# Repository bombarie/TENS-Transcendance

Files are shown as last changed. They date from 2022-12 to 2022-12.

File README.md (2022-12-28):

# TENS-Transcendance

Hardware design and code related to the development of a remotely-triggerable system of TENS muscle stimulation as part of the experimental dance / VR performance [Transcendance](https://www.theaterutrecht.nl/voorstellingen/transcendance).

The system extends an existing TENS muscle stimulator, the [Promed TENS 1000S](https://www.promed.de/soft-therapy/electrical-pain-therapy/144/promed-pain-therapy-device-tens-1000-s) and makes it controllable with OpenSoundControl (OSC) via WiFi through the use of an ESP32 microcontroller.

### Included in this repository 

**Software**
  - The [Arduino](https://www.arduino.cc/) code for the ESP32 microcontroller.
  - The code for the [Processing](https://processing.org/) sketch which served as a proxy between the ESP32 and a [TouchDesigner](https://derivative.ca/) patch (not by me) that was heavily integrating most of the performance.

**Hardware**
- The hardware designs to split a single TENS output channel to up to 16 different target locations. The PCB was designed in [KiCad](https://www.kicad.org/) 6.0.
- The additional libraries used in KiCad while designing the PCB are included in the repository.

### Dependencies

The software dependencies are enumerated in the Arduino and Processing folders.

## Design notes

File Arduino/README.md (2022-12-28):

# Arduino code

The sketch _Transcendence\_v06\_improved\_feedback\_to\_p5_ is the most recent.

### Hardware

The target device for this code is the [DOIT ESP32 DEVKIT V1](https://grobotronics.com/esp32-development-board-devkit-v1.html?sl=en) ESP32.

In the Arduino environment the ESP32 package 2.0.5 was used.

DOIT ESP32 DEVKIT V1 pinout

### Dependencies

- the WiFi + OSC library for the ESP32: [https://github.com/hideakitai/ArduinoOSC](https://github.com/hideakitai/ArduinoOSC)
- the code for addressing the CD74HC4067 16-channel multiplexer was taken from [http://adam-meyer.com/arduino/CD74HC4067](http://adam-meyer.com/arduino/CD74HC4067)
- the code for the MCP42100 digital potentiometer from DFRobot was taken from their product wiki: [https://wiki.dfrobot.com/Dual_Digital_Pot__100K__SKU__DFR0520#target_4](https://wiki.dfrobot.com/Dual_Digital_Pot__100K__SKU__DFR0520#target_4)

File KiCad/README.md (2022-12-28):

# KiCad designs

For this project we used a [Promed TENS 1000S](https://www.promed.de/soft-therapy/electrical-pain-therapy/144/promed-pain-therapy-device-tens-1000-s) TENS muscle stimulator, however there was a need to create multiple outputs, with these not needing to be active simultaneously. The TENS Output Board was designed in KiCad 6.x to support this use case. It houses a [CD74HC4067 16-channel multiplexer](https://www.sparkfun.com/products/9056) board and the switching is done using [Vishay VOR1142A6](https://www.digikey.com/en/products/detail/vishay-semiconductor-opto-division/VOR1142A6/6174564) mosfet relays.

Pressed for time the board was designed with ample room for further miniaturisation. Using solely through-hole components and spaced widely it has a distinctly oldschool look which I don't hate :)

### board layout
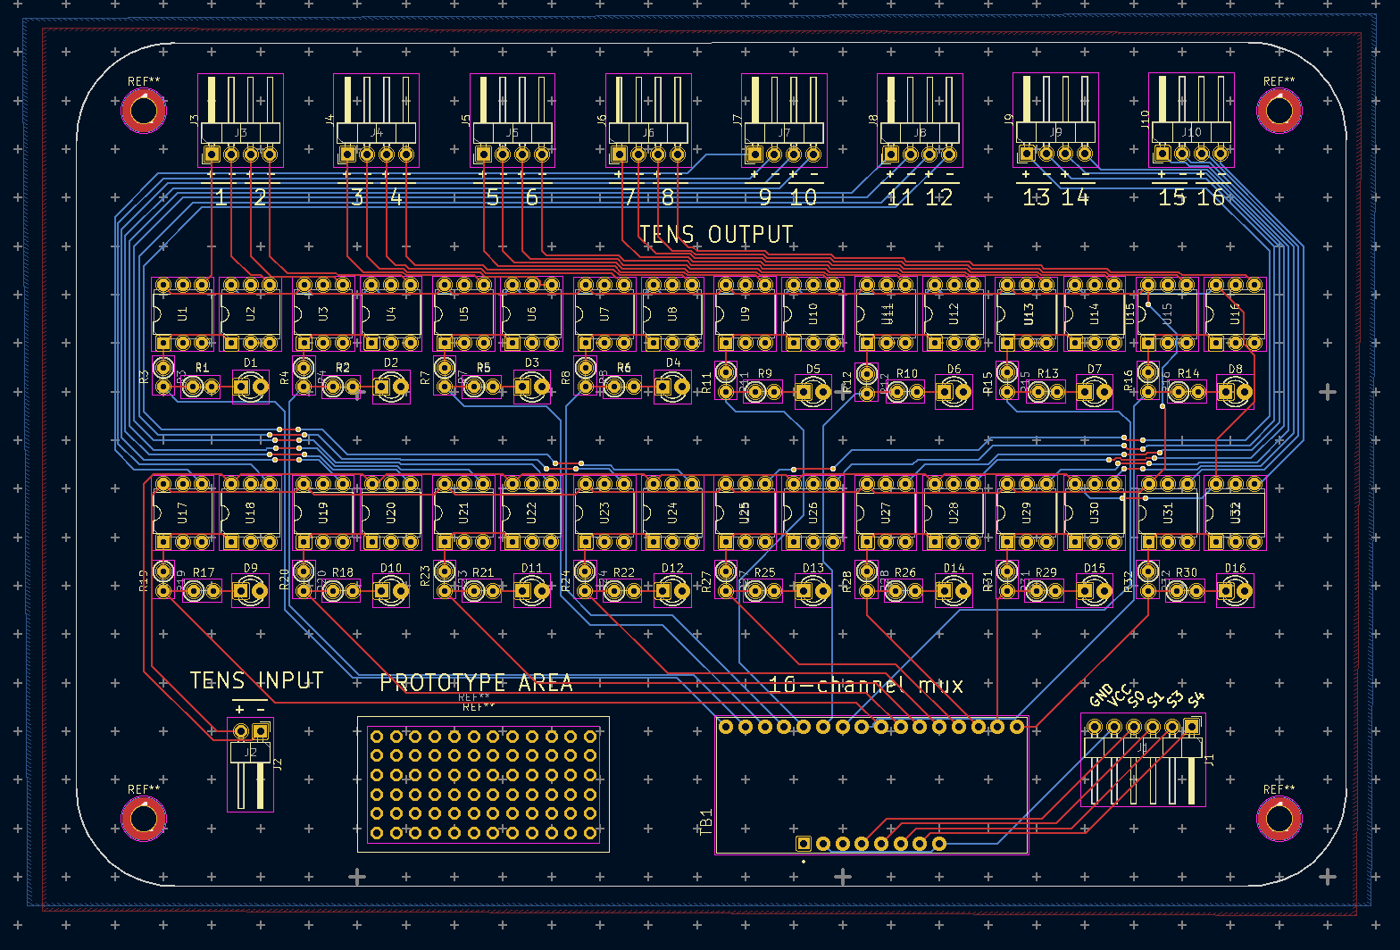
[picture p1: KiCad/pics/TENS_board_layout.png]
TENS switching board layout


### 3d preview
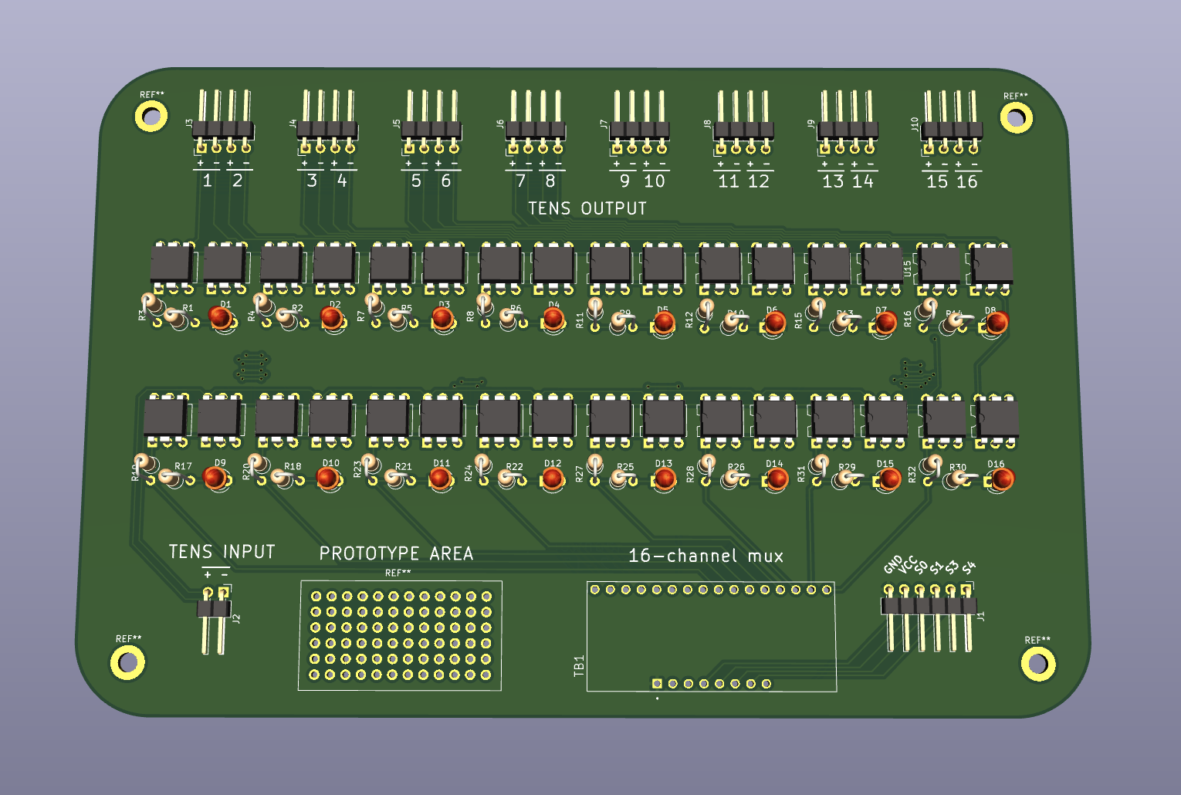
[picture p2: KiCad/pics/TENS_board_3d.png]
TENS switching board 3d preview


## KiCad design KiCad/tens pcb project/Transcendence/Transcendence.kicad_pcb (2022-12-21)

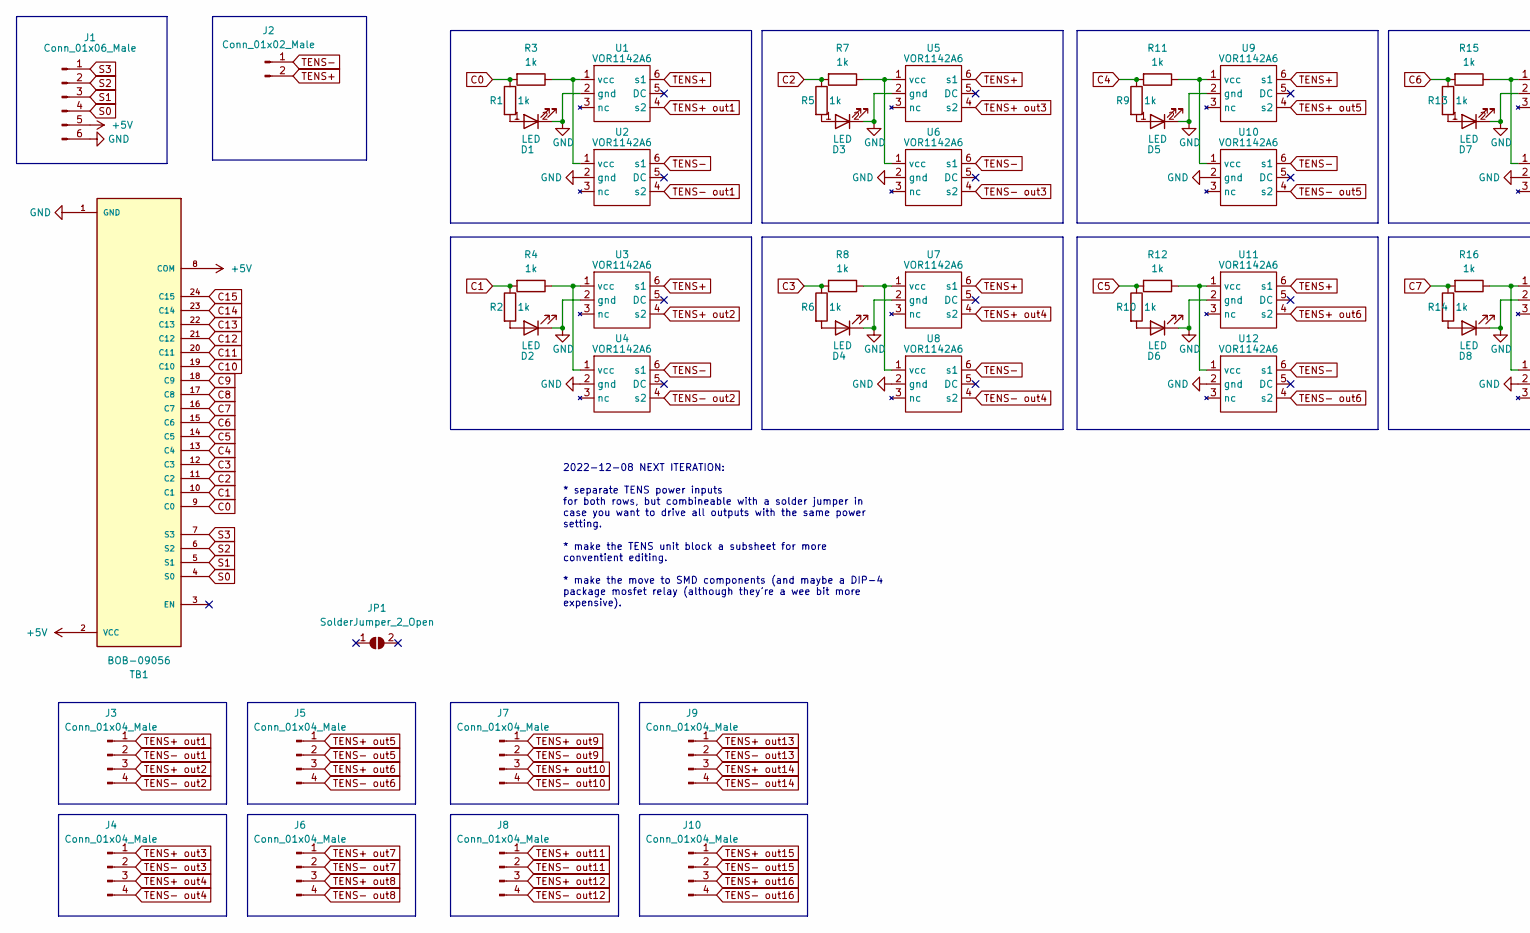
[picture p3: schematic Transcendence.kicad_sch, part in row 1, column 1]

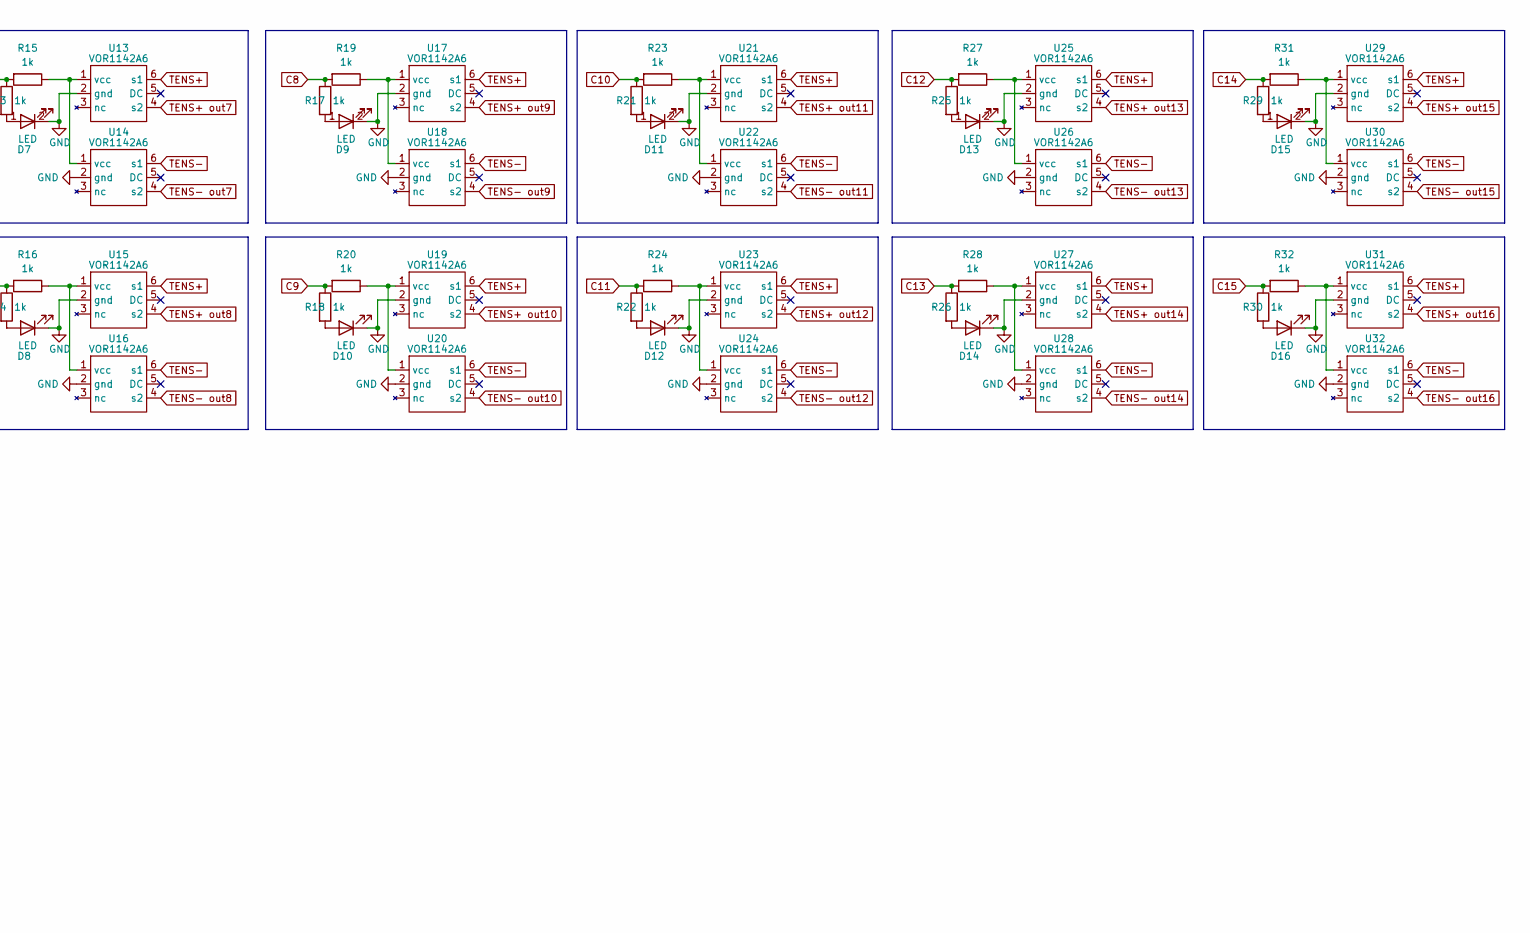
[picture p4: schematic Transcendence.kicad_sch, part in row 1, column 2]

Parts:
D1, D2, D3, D4, D5, D6, D7, D8, D9, D10, D11, D12, D13, D14, D15, D16: LED; LED_D3.0mm
J1: Conn_01x06_Male; PinHeader_1x06_P2.54mm_Horizontal
J2: Conn_01x02_Male; PinHeader_1x02_P2.54mm_Horizontal
J3, J4, J5, J6, J7, J8, J9, J10: Conn_01x04_Male; PinHeader_1x04_P2.54mm_Horizontal
JP1: SolderJumper_2_Open; SolderJumper-2_P1.3mm_Open_Pad1.0x1.5mm
R1, R2, R3, R4, R5, R6, R7, R8, R9, R10, R11, R12, R13, R14, R15, R16, R17, R18, R19, R20, R21, R22, R23, R24, R25, R26, R27, R28, R29, R30, R31, R32: 1k; R_Axial_DIN0207_L6.3mm_D2.5mm_P2.54mm_Vertical
TB1: BOB-09056; XDCR_BOB-09056; PARTREV N/A
U1, U2, U3, U4, U5, U6, U7, U8, U9, U10, U11, U12, U13, U14, U15, U16, U17, U18, U19, U20, U21, U22, U23, U24, U25, U26, U27, U28, U29, U30, U31, U32: VOR1142A6; DIP-6_W7.62mm

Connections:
+5V: J1.5, TB1.2 (VCC), TB1.8 (COM)
C0: R1.1, R3.2, TB1.9 (C0)
C1: R2.1, R4.2, TB1.10 (C1)
C2: R5.1, R7.2, TB1.11 (C2)
C3: R6.1, R8.2, TB1.12 (C3)
C4: R9.1, R11.2, TB1.13 (C4)
C5: R10.1, R12.2, TB1.14 (C5)
C6: R13.1, R15.2, TB1.15 (C6)
C7: R14.1, R16.2, TB1.16 (C7)
C8: R17.1, R19.2, TB1.17 (C8)
C9: R18.1, R20.2, TB1.18 (C9)
C10: R21.1, R23.2, TB1.19 (C10)
C11: R22.1, R24.2, TB1.20 (C11)
C12: R25.1, R27.2, TB1.21 (C12)
C13: R26.1, R28.2, TB1.22 (C13)
C14: R29.1, R31.2, TB1.23 (C14)
C15: R30.1, R32.2, TB1.24 (C15)
GND: D1.2 (K), D2.2 (K), D3.2 (K), D4.2 (K), D5.2 (K), D6.2 (K), D7.2 (K), D8.2 (K), D9.2 (K), D10.2 (K), D11.2 (K), D12.2 (K), D13.2 (K), D14.2 (K), D15.2 (K), D16.2 (K), J1.6, TB1.1 (GND), U1.2 (gnd), U2.2 (gnd), U3.2 (gnd), U4.2 (gnd), U5.2 (gnd), U6.2 (gnd), U7.2 (gnd), U8.2 (gnd), U9.2 (gnd), U10.2 (gnd), U11.2 (gnd), U12.2 (gnd), U13.2 (gnd), U14.2 (gnd), U15.2 (gnd), U16.2 (gnd), U17.2 (gnd), U18.2 (gnd), U19.2 (gnd), U20.2 (gnd), U21.2 (gnd), U22.2 (gnd), U23.2 (gnd), U24.2 (gnd), U25.2 (gnd), U26.2 (gnd), U27.2 (gnd), U28.2 (gnd), U29.2 (gnd), U30.2 (gnd), U31.2 (gnd), U32.2 (gnd)
unnamed: D1.1 (A), R1.2
unnamed: D2.1 (A), R2.2
unnamed: D3.1 (A), R5.2
unnamed: D4.1 (A), R6.2
unnamed: D5.1 (A), R9.2
unnamed: D6.1 (A), R10.2
unnamed: D7.1 (A), R13.2
unnamed: D8.1 (A), R14.2
unnamed: D9.1 (A), R17.2
unnamed: D10.1 (A), R18.2
unnamed: D11.1 (A), R21.2
unnamed: D12.1 (A), R22.2
unnamed: D13.1 (A), R25.2
unnamed: D14.1 (A), R26.2
unnamed: D15.1 (A), R29.2
unnamed: D16.1 (A), R30.2
unnamed: R3.1, U1.1 (vcc), U2.1 (vcc)
unnamed: R4.1, U3.1 (vcc), U4.1 (vcc)
unnamed: R7.1, U5.1 (vcc), U6.1 (vcc)
unnamed: R8.1, U7.1 (vcc), U8.1 (vcc)
unnamed: R11.1, U9.1 (vcc), U10.1 (vcc)
unnamed: R12.1, U11.1 (vcc), U12.1 (vcc)
unnamed: R15.1, U13.1 (vcc), U14.1 (vcc)
unnamed: R16.1, U15.1 (vcc), U16.1 (vcc)
unnamed: R19.1, U17.1 (vcc), U18.1 (vcc)
unnamed: R20.1, U19.1 (vcc), U20.1 (vcc)
unnamed: R23.1, U21.1 (vcc), U22.1 (vcc)
unnamed: R24.1, U23.1 (vcc), U24.1 (vcc)
unnamed: R27.1, U25.1 (vcc), U26.1 (vcc)
unnamed: R28.1, U27.1 (vcc), U28.1 (vcc)
unnamed: R31.1, U29.1 (vcc), U30.1 (vcc)
unnamed: R32.1, U31.1 (vcc), U32.1 (vcc)
S0: J1.4, TB1.4 (S0)
S1: J1.3, TB1.5 (S1)
S2: J1.2, TB1.6 (S2)
S3: J1.1, TB1.7 (S3)
TENS+: J2.2, U1.6 (s1), U3.6 (s1), U5.6 (s1), U7.6 (s1), U9.6 (s1), U11.6 (s1), U13.6 (s1), U15.6 (s1), U17.6 (s1), U19.6 (s1), U21.6 (s1), U23.6 (s1), U25.6 (s1), U27.6 (s1), U29.6 (s1), U31.6 (s1)
TENS+ out1: J3.1, U1.4 (s2)
TENS+ out2: J3.3, U3.4 (s2)
TENS+ out3: J4.1, U5.4 (s2)
TENS+ out4: J4.3, U7.4 (s2)
TENS+ out5: J5.1, U9.4 (s2)
TENS+ out6: J5.3, U11.4 (s2)
TENS+ out7: J6.1, U13.4 (s2)
TENS+ out8: J6.3, U15.4 (s2)
TENS+ out9: J7.1, U17.4 (s2)
TENS+ out10: J7.3, U19.4 (s2)
TENS+ out11: J8.1, U21.4 (s2)
TENS+ out12: J8.3, U23.4 (s2)
TENS+ out13: J9.1, U25.4 (s2)
TENS+ out14: J9.3, U27.4 (s2)
TENS+ out15: J10.1, U29.4 (s2)
TENS+ out16: J10.3, U31.4 (s2)
TENS-: J2.1, U2.6 (s1), U4.6 (s1), U6.6 (s1), U8.6 (s1), U10.6 (s1), U12.6 (s1), U14.6 (s1), U16.6 (s1), U18.6 (s1), U20.6 (s1), U22.6 (s1), U24.6 (s1), U26.6 (s1), U28.6 (s1), U30.6 (s1), U32.6 (s1)
TENS- out1: J3.2, U2.4 (s2)
TENS- out2: J3.4, U4.4 (s2)
TENS- out3: J4.2, U6.4 (s2)
TENS- out4: J4.4, U8.4 (s2)
TENS- out5: J5.2, U10.4 (s2)
TENS- out6: J5.4, U12.4 (s2)
TENS- out7: J6.2, U14.4 (s2)
TENS- out8: J6.4, U16.4 (s2)
TENS- out9: J7.2, U18.4 (s2)
TENS- out10: J7.4, U20.4 (s2)
TENS- out11: J8.2, U22.4 (s2)
TENS- out12: J8.4, U24.4 (s2)
TENS- out13: J9.2, U26.4 (s2)
TENS- out14: J9.4, U28.4 (s2)
TENS- out15: J10.2, U30.4 (s2)
TENS- out16: J10.4, U32.4 (s2)

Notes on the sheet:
2022-12-08 NEXT ITERATION: * separate TENS power inputs for both rows, but combineable with a solder jumper in case you want to drive all outputs with the same power setting. * make the TENS unit block a subsheet for more conventient editing. * make the move to SMD components (and maybe a DIP-4 pac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

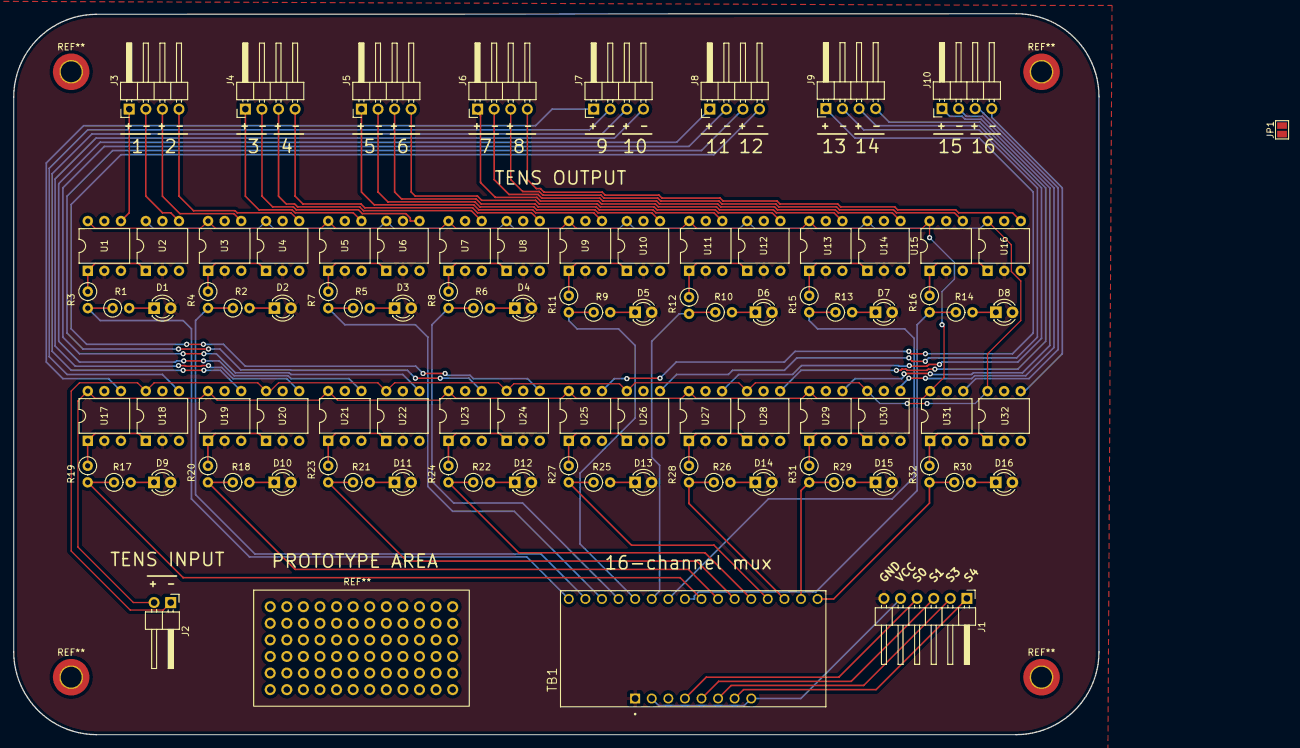
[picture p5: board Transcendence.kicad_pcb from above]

Board: 2 copper layers, 166.2 x 110.4 mm, 92 parts (0 on the bottom side), 88 nets.

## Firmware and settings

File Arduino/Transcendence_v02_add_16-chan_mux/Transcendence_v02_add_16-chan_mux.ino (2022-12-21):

// #define ARDUINOOSC_DEBUGLOG_ENABLE

// Please include ArduinoOSCWiFi.h to use ArduinoOSC on the platform
// which can use both WiFi and Ethernet
#include <ArduinoOSCWiFi.h>
// this is also valid for other platforms which can use only WiFi
// #include <ArduinoOSC.h>

#include <SPI.h>

/***********************PIN Definitions*************************/
// set pin 10 as the slave select (SS) for the digital pot
// for using Arduino UNO
//const int CS_PIN = 10; // Arduino Nano
const int CS_PIN = 5; // Doit ESP32 Wroom
//const int CS_PIN = 15; // Wemos D1 Mini

/***********************MCP42XXX Commands************************/
//potentiometer select byte
const int POT0_SEL = 0x11;
const int POT1_SEL = 0x12;
const int BOTH_POT_SEL = 0x13;

//shutdown the device to put it into power-saving mode.
//In this mode, terminal A is open-circuited and the B and W terminals are shorted together.
//send new command and value to exit shutdowm mode.
const int POT0_SHUTDOWN = 0x21;
const int POT1_SHUTDOWN = 0x22;
const int BOTH_POT_SHUTDOWN = 0x23;

/***********************Customized Varialbes**********************/
//resistance value byte (0 - 255)
//The wiper is reset to the mid-scale position upon power-up, i.e. POT0_Dn = POT1_Dn = 128
int POT0_Dn = 128;
int POT1_Dn = 128;
int BOTH_POT_Dn = 128;

// WiFi @ Theater Utrecht
//const char* ssid = "pkat";
//const char* pwd = "th3@t3r1";

// WiFi @ home
const char* ssid = "WormKoning";
const char* pwd = "dingflofbips";

// @home
const IPAddress ip(192, 168, 1, 201);
const IPAddress gateway(192, 168, 1, 1);

// @theater utrecht
//const IPAddress ip(192, 168, 72, 201);
//const IPAddress gateway(192, 168, 72, 1);
const IPAddress subnet(255, 255, 255, 0);

// for ArduinoOSC
//const char* host = "192.168.72.185"; // remote host @theater utrecht
const char* host = "192.168.1.147"; // remote host @home
const int recv_port = 54321;
const int bind_port = 54345;
const int send_port = 55555;
const int publish_port = 54445;

// Mux control pins (esp32)
static byte s0 = 26;
static byte s1 = 25;
static byte s2 = 33;
static byte s3 = 32;

byte sigIndex = 0; // mux output channel

int IdToChannel[4] = { 0, 1, 2, 3 };

// send / receive varibales
int i;
float f;
String s;

long startPulseTime;
int _pulseDuration;
bool IsPulsing = false;

// SHOULD BE TRUE (further down the line)
bool bUseHeartbeat = false;



int currTriggerID;
float pulseWidth = 0.0;     // range [0.0, 1.0] -> in reality maps to [30µs, 260µs]
float pulseFrequency = 0.0; // range [0.0, 1.0] -> in reality maps to [2Hz, 150Hz]
float pulseStrength = 0.0;  // range [0.0, 1.0] -> in reality maps to [0V, 75V]
int pulseDuration = 0;      // milliseconds
void onTriggerReceived(const OscMessage& m) {
  int id = m.arg<int>(0);
  pulseWidth = m.arg<float>(1);
  pulseFrequency = m.arg<float>(2);
  pulseStrength = m.arg<float>(3);
  pulseDuration = m.arg<int>(4);


  //  Serial.print(m.remoteIP());
  //  Serial.print(" ");
  //  Serial.print(m.remotePort());
  //  Serial.print(" ");
  //  Serial.print(m.size());
  //  Serial.print(" ");
  //  Serial.print(m.address());
  //  Serial.print(" ");

  Serial.print("trigger >> ");
  Serial.print(id);
  Serial.print(", ");
  Serial.print(pulseWidth);
  Serial.print(", ");
  Serial.print(pulseFrequency);
  Serial.print(", ");
  Serial.print(pulseStrength);
  Serial.print(", ");
  Serial.print(pulseDuration);
  Serial.println();

  executePulse(id, pulseWidth, pulseFrequency, pulseStrength, pulseDuration);

  //  OscWiFi.send(host, send_port, "/reply", i, f, s);
}

void updateDigiPot() {
  DigitalPotWrite(POT0_SEL, POT0_Dn);  //set the resistance of POT0
  DigitalPotWrite(POT1_SEL, POT1_Dn);  //set the resistance of POT1
}

long _prevHeartbeat;
int heartbeatTimeout = 1000;
bool bHasHeartbeat = false;
void onHeartbeatReceived(const OscMessage& m) {
  //  Serial.print(m.remoteIP());
  //  Serial.print(" ");
  //  Serial.print(m.remotePort());
  //  Serial.print(" ");
  //  Serial.print(m.size());
  //  Serial.print(" ");
  //  Serial.print(m.address());
  //  Serial.println();
  //
  _prevHeartbeat = millis();
  if (!bHasHeartbeat) {
    Serial.println("HEARTBEAT >> started receiving heartbeat");
    bHasHeartbeat = true;
  }
}

void setup() {
  Serial.begin(115200);
  delay(2000);

  // WiFi stuff (no timeout setting for WiFi)
#ifdef ESP_PLATFORM
  WiFi.disconnect(true, true);  // disable wifi, erase ap info
  delay(1000);
  WiFi.mode(WIFI_STA);
#endif
  WiFi.begin(ssid, pwd);
  WiFi.config(ip, gateway, subnet);
  while (WiFi.status() != WL_CONNECTED) {
    Serial.print(".");
    delay(500);
  }
  Serial.print("WiFi connected, IP = ");
  Serial.println(WiFi.localIP());


  // setup digital pot
  pinMode(CS_PIN, OUTPUT);  // set the CS_PIN as an output:
  SPI.begin();              // initialize SPI:

  DigitalPotWrite(BOTH_POT_SHUTDOWN, BOTH_POT_Dn);


  pinMode(LED_BUILTIN, OUTPUT);


  // init mux
  pinMode(s0, OUTPUT);
  pinMode(s1, OUTPUT);
  pinMode(s2, OUTPUT);
  pinMode(s3, OUTPUT);
  digitalWrite(s0, LOW);
  digitalWrite(s1, LOW);
  digitalWrite(s2, LOW);
  digitalWrite(s3, LOW);
  setMux(15); // 15 is off / no-connected

  OscWiFi.subscribe(recv_port, "/heartbeat", onHeartbeatReceived);
  OscWiFi.subscribe(recv_port, "/trigger", onTriggerReceived);

  startPulseTime = millis();
}

long prevMillisFast;
int updateIntervalFast = 1000 / 60;
long prevMillisSlow;
int updateIntervalSlow = 1000 / 30;

long mills;
int digipotApplyDuration = 190; // ms
bool digitpotIsSettling = false;

void loop() {
  mills = millis();

  // fast update loop
  if (mills - prevMillisFast > updateIntervalFast) {
    OscWiFi.update();  // should be called to receive + send osc

    prevMillisFast = mills;
  }


  // slow update loop
  if (mills - prevMillisSlow > updateIntervalSlow) {

    handleSerial();

    updateHeartbeat();

    if (bHasHeartbeat) {
      if (IsPulsing) {

        // cheap way to wait juuust a moment before applying the pulse
        if (digitpotIsSettling) {

          // if we have given the digipot time to settle, continue with the actual event
          if (millis() - startPulseTime > digipotApplyDuration) {
            startPulseTime += digipotApplyDuration;

            // now apply the trigger
            setMux(IdToChannel[currTriggerID] - 1);
            Serial.println("start!");

            digitpotIsSettling = false;
          }
        }
        if (!digitpotIsSettling) {
          if (millis() - startPulseTime > _pulseDuration) {
            Serial.println("finished pulsing");
            IsPulsing = false;
          }
        }
      }
    }

    // turn off
    if (!bHasHeartbeat || !IsPulsing) {
      // set mux to 0
      // [to be implemented!] set output strength low, to be safe?

      pulseWidth = .1;
      pulseFrequency = .1;
      pulseStrength = 0.0;

      setMux(15); // chan 15 is off / no-connected
    }

    //  POT0_Dn = (int)(pulseWidth * 255.0);
    //  POT1_Dn = (int)(pulseFrequency * 255.0);

    //    POT0_Dn++;
    //    POT0_Dn = POT0_Dn % 255;
    //  Serial.print(", POT0_Dn: ");
    //  Serial.println(POT0_Dn);

    //  Serial.print("pulseWidth: ");
    //  Serial.print(pulseWidth);

    updateDigiPot();


    prevMillisSlow = mills;
  }


  // FYI: how to send
  // OscWiFi.send(host, send_port, "/reply", i, f, s);

  // or do that separately
  // OscWiFi.parse(); // to receive osc
  // OscWiFi.post(); // to publish osc
}

void updateHeartbeat() {
  if (millis() - _prevHeartbeat > heartbeatTimeout) {
    if (bHasHeartbeat) {
      Serial.println("HEARTBEAT >> stopped receiving heartbeat");

      bHasHeartbeat = false;
    }
  }
}

bool handleSerial() {
  if (Serial.available()) {
    //    Serial.println("SERIAL");
    char c = Serial.read();
    switch (c) {
      case '1':
        Serial.print("move pot 1 up >> value: ");
        if (POT0_Dn < 255) {
          POT0_Dn += 16;
        }
        Serial.println(POT0_Dn);
        return true;
        break;
      case '2':
        Serial.print("move pot 2 up >> value: ");
        if (POT1_Dn < 255) {
          POT1_Dn += 16;
        }
        Serial.println(POT1_Dn);
        return true;
        break;
      case '3':
        Serial.print("move pot 1 down >> value: ");
        if (POT0_Dn > 0) {
          POT0_Dn -= 16;
        }
        Serial.println(POT0_Dn);
        return true;
        break;
      case '4':
        Serial.print("move pot 2 down >> value: ");
        if (POT1_Dn > 0) {
          POT1_Dn -= 16;
        }
        Serial.println(POT1_Dn);
        return true;
        break;
    }

    while (Serial.available()) Serial.read();
  }
  return false;
}

void executePulse(int id, float pWidth, float pFreq, float pStrength, int duration) {
  // set right channel on 16-chan mux
  // set parameters of the digital pot
  // [to be implemented later!] set the strength
  // record the time now
  startPulseTime = millis();
  _pulseDuration = duration;
  IsPulsing = true;

  POT0_Dn = (int)(pWidth * 255.0);
  POT1_Dn = (int)(pFreq * 255.0);
  updateDigiPot();
  digitpotIsSettling = true;

  //  delay(500); // does this help the digipot update on time?

  id = constrain(id, 1, 16);
  currTriggerID = id;

  Serial.println("pre-start...");
  //  Serial.print("starting pulse at id ");
  //  Serial.print(id);
  //  Serial.print(", width ");
  //  Serial.print(pWidth);
  //  Serial.print(", frequency ");
  //  Serial.print(pFreq);
  //  Serial.print(", strength ");
  //  Serial.print(pStrength);
  //  Serial.print(", duration ");
  //  Serial.println(duration);
}





void setMux(int channel) {
  int controlPin[] = {s0, s1, s2, s3};

  int muxChannel[16][4] = {
    {0, 0, 0, 0}, //channel 0
    {1, 0, 0, 0}, //channel 1
    {0, 1, 0, 0}, //channel 2
    {1, 1, 0, 0}, //channel 3
    {0, 0, 1, 0}, //channel 4
    {1, 0, 1, 0}, //channel 5
    {0, 1, 1, 0}, //channel 6
    {1, 1, 1, 0}, //channel 7
    {0, 0, 0, 1}, //channel 8
    {1, 0, 0, 1}, //channel 9
    {0, 1, 0, 1}, //channel 10
    {1, 1, 0, 1}, //channel 11
    {0, 0, 1, 1}, //channel 12
    {1, 0, 1, 1}, //channel 13
    {0, 1, 1, 1}, //channel 14
    {1, 1, 1, 1} //channel 15
  };

  //loop through the 4 sig
  for (int i = 0; i < 4; i ++) {
    digitalWrite(controlPin[i], muxChannel[channel][i]);
  }

  //read the value at the SIG pin
  //  int val = digitalWrite(SIG_pin);

  //return the value
  //  return val;
}






//Function Declaration
void DigitalPotTransfer(int cmd, int value);  //send the command and the resistance value through SPI

void DigitalPotWrite(int cmd, int val) {
  //  SPI.beginTransaction(SPISettings(SCK, MSBFIRST, SPI_MODE0));
  // constrain input value within 0 - 255
  val = constrain(val, 0, 255);
  // set the CS pin to low to select the chip:
  digitalWrite(CS_PIN, LOW);
  // send the command and value via SPI:
  SPI.transfer(cmd);
  SPI.transfer(val);
  // Set the CS pin high to execute the command:
  digitalWrite(CS_PIN, HIGH);
  //  SPI.endTransaction();
}

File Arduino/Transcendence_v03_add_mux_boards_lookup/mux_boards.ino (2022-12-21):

void initTENSIDToBoardPortMapping() {
  id_to_boardport[1] = IdToBoardPort(0, 1);
  id_to_boardport[2] = IdToBoardPort(0, 2);
  id_to_boardport[3] = IdToBoardPort(0, 3);
  id_to_boardport[4] = IdToBoardPort(0, 4);
  id_to_boardport[5] = IdToBoardPort(0, 5);
  id_to_boardport[6] = IdToBoardPort(0, 6);
  id_to_boardport[7] = IdToBoardPort(0, 7);
  id_to_boardport[8] = IdToBoardPort(0, 8);
  id_to_boardport[9] = IdToBoardPort(1, 1);
  id_to_boardport[10] = IdToBoardPort(1, 2);
  id_to_boardport[11] = IdToBoardPort(1, 3);
  id_to_boardport[12] = IdToBoardPort(1, 4);
  id_to_boardport[13] = IdToBoardPort(1, 5);
  id_to_boardport[14] = IdToBoardPort(1, 6);
  id_to_boardport[15] = IdToBoardPort(1, 7);
  id_to_boardport[16] = IdToBoardPort(1, 8);

/*
  id_to_boardport[1] = IdToBoardPort(0, 15);
  id_to_boardport[2] = IdToBoardPort(0, 16);
  id_to_boardport[3] = IdToBoardPort(0, 4);
  id_to_boardport[4] = IdToBoardPort(0, 5);
  id_to_boardport[5] = IdToBoardPort(0, 7);
  id_to_boardport[6] = IdToBoardPort(0, 6);
  id_to_boardport[7] = IdToBoardPort(0, 11);
  id_to_boardport[8] = IdToBoardPort(0, 9);
  id_to_boardport[9] = IdToBoardPort(0, 8);
  id_to_boardport[10] = IdToBoardPort(0, 12);
  id_to_boardport[11] = IdToBoardPort(0, 13);
  id_to_boardport[12] = IdToBoardPort(1, 15);
  id_to_boardport[13] = IdToBoardPort(1, 5);
  id_to_boardport[14] = IdToBoardPort(1, 2);
  id_to_boardport[15] = IdToBoardPort(1, 16);
  id_to_boardport[16] = IdToBoardPort(1, 1);
  id_to_boardport[17] = IdToBoardPort(2, 5);
  id_to_boardport[18] = IdToBoardPort(2, 7);
  id_to_boardport[19] = IdToBoardPort(2, 9);
  id_to_boardport[20] = IdToBoardPort(2, 11);
  id_to_boardport[21] = IdToBoardPort(2, 2);
*/  
}

void initMuxBoards() {

  pinMode(mux_1_s0, OUTPUT);
  pinMode(mux_1_s1, OUTPUT);
  pinMode(mux_1_s2, OUTPUT);
  pinMode(mux_1_s3, OUTPUT);
  digitalWrite(mux_1_s0, LOW);
  digitalWrite(mux_1_s1, LOW);
  digitalWrite(mux_1_s2, LOW);
  digitalWrite(mux_1_s3, LOW);
  
  pinMode(mux_2_s0, OUTPUT);
  pinMode(mux_2_s1, OUTPUT);
  pinMode(mux_2_s2, OUTPUT);
  pinMode(mux_2_s3, OUTPUT);
  digitalWrite(mux_2_s0, LOW);
  digitalWrite(mux_2_s1, LOW);
  digitalWrite(mux_2_s2, LOW);
  digitalWrite(mux_2_s3, LOW);
  
//  pinMode(mux_3_s0, OUTPUT);
//  pinMode(mux_3_s1, OUTPUT);
//  pinMode(mux_3_s2, OUTPUT);
//  pinMode(mux_3_s3, OUTPUT);
//  digitalWrite(mux_3_s0, LOW);
//  digitalWrite(mux_3_s1, LOW);
//  digitalWrite(mux_3_s2, LOW);
//  digitalWrite(mux_3_s3, LOW);
  
  setMux_1(MUX_OFF_PIN);
  setMux_2(MUX_OFF_PIN);
//  setMux_3(MUX_OFF_PIN);

}


void allMuxesOff() {
  setMux_1(MUX_OFF_PIN);
  setMux_2(MUX_OFF_PIN);
  //  setMux_3(MUX_OFF_PIN);
  
}

void setMux_1(int channel) {
  int controlPin[] = {mux_1_s0, mux_1_s1, mux_1_s2, mux_1_s3};

  int muxChannel[16][4] = {
    {0, 0, 0, 0}, //channel 0
    {1, 0, 0, 0}, //channel 1
    {0, 1, 0, 0}, //channel 2
    {1, 1, 0, 0}, //channel 3
    {0, 0, 1, 0}, //channel 4
    {1, 0, 1, 0}, //channel 5
    {0, 1, 1, 0}, //channel 6
    {1, 1, 1, 0}, //channel 7
    {0, 0, 0, 1}, //channel 8
    {1, 0, 0, 1}, //channel 9
    {0, 1, 0, 1}, //channel 10
    {1, 1, 0, 1}, //channel 11
    {0, 0, 1, 1}, //channel 12
    {1, 0, 1, 1}, //channel 13
    {0, 1, 1, 1}, //channel 14
    {1, 1, 1, 1} //channel 15
  };

  //loop through the 4 sig
  for (int i = 0; i < 4; i ++) {
    digitalWrite(controlPin[i], muxChannel[channel][i]);
  }

}

void setMux_2(int channel) {
  int controlPin[] = {mux_2_s0, mux_2_s1, mux_2_s2, mux_2_s3};

  int muxChannel[16][4] = {
    {0, 0, 0, 0}, //channel 0
    {1, 0, 0, 0}, //channel 1
    {0, 1, 0, 0}, //channel 2
    {1, 1, 0, 0}, //channel 3
    {0, 0, 1, 0}, //channel 4
    {1, 0, 1, 0}, //channel 5
    {0, 1, 1, 0}, //channel 6
    {1, 1, 1, 0}, //channel 7
    {0, 0, 0, 1}, //channel 8
    {1, 0, 0, 1}, //channel 9
    {0, 1, 0, 1}, //channel 10
    {1, 1, 0, 1}, //channel 11
    {0, 0, 1, 1}, //channel 12
    {1, 0, 1, 1}, //channel 13
    {0, 1, 1, 1}, //channel 14
    {1, 1, 1, 1} //channel 15
  };

  //loop through the 4 sig
  for (int i = 0; i < 4; i ++) {
    digitalWrite(controlPin[i], muxChannel[channel][i]);
  }

}

void setMux_3(int channel) {
  int controlPin[] = {mux_3_s0, mux_3_s1, mux_3_s2, mux_3_s3};

  int muxChannel[16][4] = {
    {0, 0, 0, 0}, //channel 0
    {1, 0, 0, 0}, //channel 1
    {0, 1, 0, 0}, //channel 2
    {1, 1, 0, 0}, //channel 3
    {0, 0, 1, 0}, //channel 4
    {1, 0, 1, 0}, //channel 5
    {0, 1, 1, 0}, //channel 6
    {1, 1, 1, 0}, //channel 7
    {0, 0, 0, 1}, //channel 8
    {1, 0, 0, 1}, //channel 9
    {0, 1, 0, 1}, //channel 10
    {1, 1, 0, 1}, //channel 11
    {0, 0, 1, 1}, //channel 12
    {1, 0, 1, 1}, //channel 13
    {0, 1, 1, 1}, //channel 14
    {1, 1, 1, 1} //channel 15
  };

  //loop through the 4 sig
  for (int i = 0; i < 4; i ++) {
    digitalWrite(controlPin[i], muxChannel[channel][i]);
  }

}

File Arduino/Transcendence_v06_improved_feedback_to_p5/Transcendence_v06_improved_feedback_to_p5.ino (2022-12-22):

#include "variables.h"



/*******   WIFI settings   ******************************/

// SSID and password of the wifi access point
const char* ssid = "ORBI06";
const char* pwd = "livelyprairie064";
 
// IP address for the Arduino
const IPAddress ip(10, 0, 0, 88);
const IPAddress gateway(10, 0, 0, 1);

/*******************************************************/




// #define ARDUINOOSC_DEBUGLOG_ENABLE

// Please include ArduinoOSCWiFi.h to use ArduinoOSC on the platform
// which can use both WiFi and Ethernet
#include <ArduinoOSCWiFi.h>
// this is also valid for other platforms which can use only WiFi
// #include <ArduinoOSC.h>






// send / receive varibales
int i;
float f;
String s;

long startPulseTime;
int _pulseDuration;
bool IsPulsing = false;


// SHOULD BE TRUE further down the line but I can see me
// disabling this during testing periods to prevent HAVING
// to have an active heartbeat.
bool bUseHeartbeat = false;


int currTriggerID;
int currTriggerIDs[2];
float pulseWidth = 0.0;     // range [0.0, 1.0] -> in reality maps to [30µs, 260µs]
float pulseFrequency = 0.0; // range [0.0, 1.0] -> in reality maps to [2Hz, 150Hz]
float pulseStrength = 0.0;  // range [0.0, 1.0] -> in reality maps to [0V, 75V]
int pulseDuration = 0;      // milliseconds

int digipotApplyDuration = 190; // ms
bool digitpotIsSettling = false;

void setup() {
  Serial.begin(115200);
  delay(2000);

  initWiFi();

  initDigiPot();

  pinMode(LED_BUILTIN, OUTPUT);

  initTENSIDToBoardPortMapping();
  initMuxBoards();

  OscWiFi.subscribe(recv_port, "/heartbeat", onHeartbeatReceived);
  OscWiFi.subscribe(recv_port, "/trigger", onTriggerReceived);

  startPulseTime = millis();
}

void loop() {
  mills = millis();

  // fast update loop
  if (mills - prevMillisFast > updateIntervalFast) {
    OscWiFi.update();  // should be called to receive + send osc

    prevMillisFast = mills;
  }


  // slow update loop
  if (mills - prevMillisSlow > updateIntervalSlow) {

    handleSerial();

    updateHeartbeat();


    // TODO merge the logic of the 'IsPulsing' conditional below and the updateTENSTriggerList()
    updateTENSTriggerList();

    if (bHasHeartbeat) {
      if (IsPulsing) {

        // cheap way to wait juuust a moment before applying the pulse
        if (digitpotIsSettling) {

          // if we have given the digipot time to settle, continue with the actual event
          if (millis() - startPulseTime > digipotApplyDuration) {
            startPulseTime += digipotApplyDuration;

            // *now* apply the trigger
            // setMux_1(IdToChannel[currTriggerID] - 1);

            allMuxesOff();
            for (int i = 0; i < 2; i++) {
              if (currTriggerIDs[i] != -1) {
                setIdActive(currTriggerIDs[i]);
              }
            }
            //            setIdActive(currTriggerID);

            //            Serial.print(millis());
            //            Serial.println(" start!");

            digitpotIsSettling = false;
          }
        }
        if (!digitpotIsSettling) {
          if (millis() - startPulseTime > _pulseDuration) {
            //            Serial.print(millis());
            //            Serial.println(" finished pulsing");
            tensTriggerList[triggerListIndex].isActive = false;
            IsPulsing = false;
          }
        }
      }
    }

    // turn off
    if (!bHasHeartbeat || !IsPulsing) {
      // set mux to 0
      // [to be implemented!] *actually* set output strength low, to be safe? -> like through a relay?

      pulseWidth = .1;
      pulseFrequency = .1;
      pulseStrength = 0.0;

      allMuxesOff();
    }

    updateDigiPot();

    prevMillisSlow = mills;
  }

  // FYI: how to send
  // OscWiFi.send(host, send_port, "/reply", i, f, s);

  // or do that separately
  // OscWiFi.parse(); // to receive osc
  // OscWiFi.post(); // to publish osc
}


void updateTENSTriggerList() {
  // commented out the wait-until-make-inactive conditional -> it's handled in the main loop()
  // TODO: MERGE!

  //  if (tensTriggerList[triggerListIndex].isActive) {
  //    // wait to deactivate
  //    if (millis() - triggerTimestamp > tensTriggerList[triggerListIndex].duration) {
  //      // deactivate
  //
  //      Serial.print("Done with trigger at index ");
  //      Serial.print(triggerListIndex);
  //      Serial.print(" after ");
  //      Serial.print(millis() - triggerTimestamp);
  //      Serial.println(" ms");
  //
  //      tensTriggerList[triggerListIndex].isActive = false;
  //    }
  //  }
  if (!tensTriggerList[triggerListIndex].isActive) {
    if (triggerListActiveHeadIndex != triggerListIndex) {
      triggerListIndex++;
      triggerListIndex = triggerListIndex % triggerListLength;

      // This if statement shouldn't be necessary because a 'new index'
      // should de facto mean that a new trigger was added to the list,
      // but hey... let's double-check. In the worst case this prevents
      // some runaway event.
      if (tensTriggerList[triggerListIndex].isActive) {
        // activate
        executeTriggersAtIndex(triggerListIndex);
      }
    }
  }
}

// set the digipot and such
void setTriggerActive(byte i) {
  triggerTimestamp = millis();
  tensTriggerList[i].isActive = true;
}


// send a debug string over osc
void debugmsg(String s) {
  //  Serial.println("f:debugmsg");

  if (oscRemotePort != 0) {
    OscWiFi.send(oscRemoteIP, oscRemotePort, "/debugmsg", s);
  } else {
    Serial.println("f:debugmsg ERROR >> oscRemotePort is not initialized >> not sending");
  }
}

void updateHeartbeat() {
  if (millis() - _prevHeartbeat > heartbeatTimeout) {
    if (bHasHeartbeat) {
      //      debugmsg("HEARTBEAT >> stopped receiving heartbeat");
      Serial.println("HEARTBEAT >> stopped receiving heartbeat");

      // just to be safe -> always clear any buffered TENS triggers?
      triggerListIndex = triggerListActiveHeadIndex;
      tensTriggerList[triggerListIndex].isActive = false;

      digitalWrite(LED_BUILTIN, LOW);

      bHasHeartbeat = false;
    }
  }
}

void setIdActive(byte id) {
  Serial.println("f:setIdActive >> id: " + String(id));

  if (id > 0 && id < 22) {
    byte board = id_to_boardport[id].board;
    byte port = id_to_boardport[id].port;
    switch (board) {
      case 0:
        setMux_1(port - 1);
        break;
      case 1:
        setMux_2(port - 1);
        break;
    }
  }
}
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

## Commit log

2022-12-21 Add Arduino sketches
2022-12-21 add. KiCad project
    [Transcendence.kicad_pcb, Transcendence.kicad_sch]
2022-12-21 add KiCad external and self-made libraries
2022-12-22 add READMEs for Arduino and Processing sketches
    mainly intended to describe dependencies.
